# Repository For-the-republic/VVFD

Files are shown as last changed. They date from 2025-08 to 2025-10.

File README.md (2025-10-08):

# VVFD
 Variable VFD display driver for any electromagnet based VFD.
 made by Sam Ramsay and Luke Quigley
# PREREQUISTES

## It must have a leakage current
VFDs are funny little things, as even though the have vacumn in the name, most are not a pure vacumn. instead they have a small amount of gas in them. this is only true for larger ( or more delacite ones), and is the main operation which we are measuring to find the anode connections.

## how to tell if you have a leakage current
the best way to tell if it has a leakage current is by the datasheet. if it has **both** a current draw on the segment and grid, you have a leakage. 

the next best way to tell is by the size of the VFD. smaller VFDs tend to be pure vacumns, and dont have a leakage current. if it is a larger (or older) VFD like those found in audio amplifiers, car radios ect, it most likely has a leakage current.

the third and final way to tell is to manually check. if there is a leakage current, **there will be a small current increase when a valid grid/segment combination is found**. this is by far the best way to tell, however can be quite finnicky and so we reccomend the other ways first.

# how this works
 it detects a leakage in current across different pins, and will make an anode connection table accordingly.
  this is still in development so it might take a while to get up and running.

# setup process and PCB information
the PCB is designed to be cascaded for extra modules to fit your VFD size. each module can have 32 pins, and only requires the cascade/vfd driver components. the original board will still need the drivers, but no other ones will.
## setup information
the two values you will need to change  are:
- PINCOUNT
PINCOUNT is the number of shift registers used, starting from the main module and cascading to the right. we need to know this so we can properly push the right bits.

compile this code to your arduino, and have it plugged in to accept serial out. the arduino will print your matrix to the serial out, so its kinda important.

to set the base conditions, the the arduino runs it will go into setup mode for one minute. this gives you time to ajust the variable resistors, and make sure everything is working. **DO NOT CHANGE THE RESISTORS AFTER ONE MINUTE**, or else the ammeters wont have a base value to test off of.
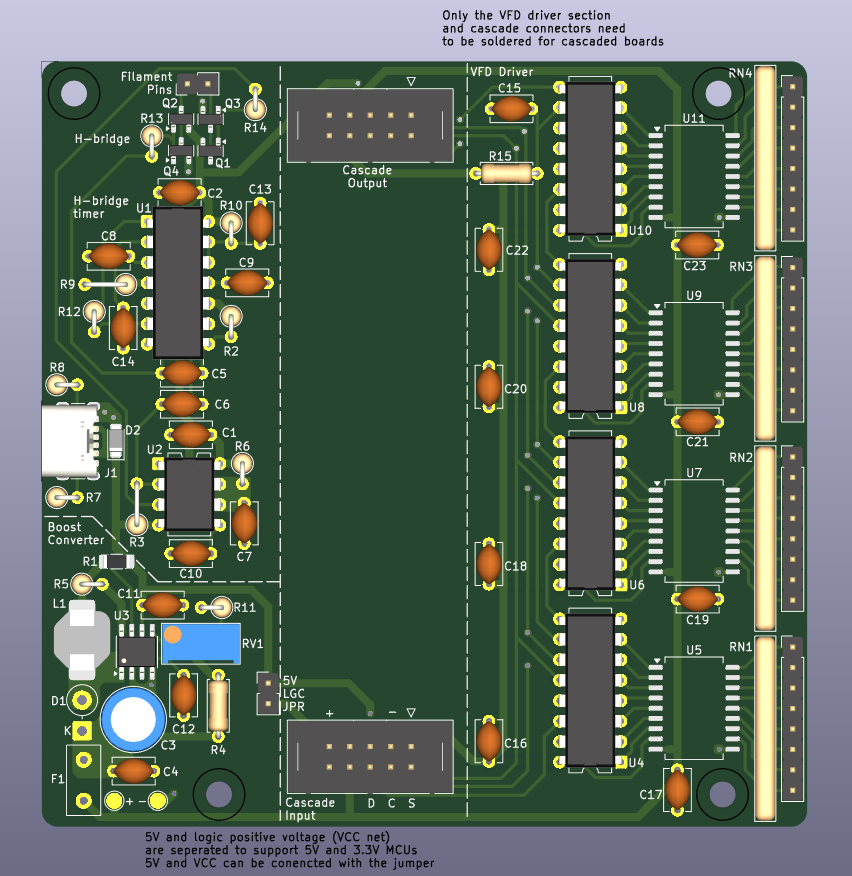
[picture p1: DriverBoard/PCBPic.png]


once this mode is done, just leave it. 
## when it has finished
once it has completed making the pinout table, it will cycle through every valid combonation and send a matrix to the serial out of the arduino.

## a note about pinouts
**if in doubt, use the pinout schematic/PCB provided**
- the AC generator pins must be both PWN pins
- the ammeter pins must be analouge
- all other pins should combos should be fine

[video of it working](https://youtu.be/ehEdY2yYjXk)

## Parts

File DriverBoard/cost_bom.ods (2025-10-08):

Reference | Qty | Value | Footprint | Master Component | Digikey Part No | Manufacturer Part No | Unit Price ($) | UC Component | Master UC Components ($) | Master DigiKey Components ($) | Cascade UC Components ($) | Cascade DigiKey Components ($) |  | User Exclude
C1,C2,C4,C11,C15,C16,C17,C18,C19,C20,C21,C22,C23 | 13 | 100n | Capacitor_THT:C_Disc_D5.1mm_W3.2mm_P5.00mm | 0 | UC |  | 0.2 | 1 | 0 | 0 | 2.6 | 0 |  | 0
C3 | 1 | 100u | Capacitor_THT:C_Radial_D8.0mm_H11.5mm_P3.50mm | 1 | 732-9051-1-ND | 860080674009 | 0.7245 | 0 | 0 | 0.7245 | 0 | 0 |  | 0
C5,C6,C8,C9,C10,C13 | 6 | 10n | Capacitor_THT:C_Disc_D5.1mm_W3.2mm_P5.00mm | 1 | UC |  | 0.2 | 1 | 1.2 | 0 | 0 | 0 |  | 0
C7,C14 | 2 | 220n | Capacitor_THT:C_Disc_D5.1mm_W3.2mm_P5.00mm | 1 | UC |  | 0.4 | 1 | 0.8 | 0 | 0 | 0 |  | 0
C12 | 1 | 330p | Capacitor_THT:C_Disc_D5.1mm_W3.2mm_P5.00mm | 1 | UC |  | 0.2 | 1 | 0.2 | 0 | 0 | 0 |  | 0
D1 | 1 | SB240L | Diode_THT:D_DO-15_P3.81mm_Vertical_KathodeUp | 1 | UC | SB240L | 0.8 | 1 | 0.8 | 0 | 0 | 0 |  | 0
D2 | 1 | SMF5V0A | Diode_SMD:D_SMF | 1 | 4878-SMF5.0ACT-ND | SMF5.0A | 0.5175 | 0 | 0 | 0.5175 | 0 | 0 |  | 0
F1 | 1 | 100mA hold | Fuse:Fuse_Littelfuse_395Series | 1 | UC | TRF250-120 | 1.2 | 1 | 1.2 | 0 | 0 | 0 |  | 0
J1 | 1 | USB_C_Receptacle_USB2.0_14P | Connector_USB:USB_C_Receptacle_GCT_USB4125-xx-x-0190_6P_TopMnt_Horizontal | 1 | 2223-UJC-H-G-SMT-P6-TRCT-ND | UJC-H-G-SMT-P6-TR | 0.851 | 0 | 0 | 0.851 | 0 | 0 |  | 0
J2 | 1 | Conn_01x02_Pin | Connector_PinHeader_2.54mm:PinHeader_1x02_P2.54mm_Vertical | 1 | UC |  | 0 | 1 | 0 | 0 | 0 | 0 |  | 0
J3,J4 | 2 | Conn_02x05_Counter_Clockwise | Connector_IDC:IDC-Header_2x05_P2.54mm_Vertical | 0 | UC |  | 0.45 | 1 | 0 | 0 | 0.9 | 0 |  | 0
J5,J6,J7,J8 | 4 | Conn_01x08_Pin | Connector_PinHeader_2.54mm:PinHeader_1x08_P2.54mm_Vertical | 0 | UC |  | 0.15 | 1 | 0 | 0 | 0.6 | 0 |  | 0
JP1 | 1 | Jumper_2_Open | Connector_PinHeader_2.54mm:PinHeader_1x02_P2.54mm_Vertical | 1 | UC |  | 0 | 1 | 0 | 0 | 0 | 0 |  | 0
L1 | 1 | 100uH | Custom:SPM7054VT-D | 1 | 445-180962-1-ND | SPM7054VT-101M-D | 2.6105 | 0 | 0 | 2.6105 | 0 | 0 |  | 0
Q1,Q2 | 2 | DMG2305UX | Package_TO_SOT_SMD:SOT-23 | 1 | DMG2305UX-7DICT-ND | DMG2305UX-7 | 0.3565 | 0 | 0 | 0.713 | 0 | 0 |  | 0
Q3,Q4 | 2 | SL3402 | Package_TO_SOT_SMD:SOT-23 | 1 | 5399-SL3402CT-ND | SL3402 | 0.3335 | 0 | 0 | 0.667 | 0 | 0 |  | 0
R1 | 1 | 0.2R | Resistor_SMD:R_1206_3216Metric_Pad1.30x1.75mm_HandSolder | 1 | 283-MFHA1206R2000FCCT-ND | MFHA1206R2000FC | 0.506 | 0 | 0 | 0.506 | 0 | 0 |  | 0
R2 | 1 | 3k3 | Resistor_THT:R_Axial_DIN0207_L6.3mm_D2.5mm_P2.54mm_Vertical | 1 | UC |  | 0 | 1 | 0 | 0 | 0 | 0 |  | 0
R3 | 1 | 3k3 | Resistor_THT:R_Axial_DIN0207_L6.3mm_D2.5mm_P5.08mm_Vertical | 1 | UC |  | 0 | 1 | 0 | 0 | 0 | 0 |  | 0
R4 | 1 | 100k | Resistor_THT:R_Axial_DIN0207_L6.3mm_D2.5mm_P7.62mm_Horizontal | 1 | UC |  | 0 | 1 | 0 | 0 | 0 | 0 |  | 0
R5 | 1 | 180R | Resistor_THT:R_Axial_DIN0207_L6.3mm_D2.5mm_P2.54mm_Vertical | 1 | UC |  | 0 | 1 | 0 | 0 | 0 | 0 |  | 0
R6 | 1 | 39k | Resistor_THT:R_Axial_DIN0207_L6.3mm_D2.5mm_P2.54mm_Vertical | 1 | UC |  | 0 | 1 | 0 | 0 | 0 | 0 |  | 0
R7,R8 | 2 | 5k1 | Resistor_THT:R_Axial_DIN0207_L6.3mm_D2.5mm_P2.54mm_Vertical | 1 | UC |  | 0 | 1 | 0 | 0 | 0 | 0 |  | 0
R9 | 1 | 1k | Resistor_THT:R_Axial_DIN0207_L6.3mm_D2.5mm_P5.08mm_Vertical | 1 | UC |  | 0 | 1 | 0 | 0 | 0 | 0 |  | 0
R10 | 1 | 10k | Resistor_THT:R_Axial_DIN0207_L6.3mm_D2.5mm_P2.54mm_Vertical | 1 | UC |  | 0 | 1 | 0 | 0 | 0 | 0 |  | 0
R11 | 1 | 3k9 | Resistor_THT:R_Axial_DIN0207_L6.3mm_D2.5mm_P2.54mm_Vertical | 1 | UC |  | 0 | 1 | 0 | 0 | 0 | 0 |  | 0
R12 | 1 | 68k | Resistor_THT:R_Axial_DIN0207_L6.3mm_D2.5mm_P2.54mm_Vertical | 1 | UC |  | 0 | 1 | 0 | 0 | 0 | 0 |  | 0
R13,R14 | 2 | 2K2 | Resistor_THT:R_Axial_DIN0207_L6.3mm_D2.5mm_P2.54mm_Vertical | 1 | UC |  | 0 | 1 | 0 | 0 | 0 | 0 |  | 0
R15 | 1 | 10k | Resistor_THT:R_Axial_DIN0207_L6.3mm_D2.5mm_P7.62mm_Horizontal | 1 | UC |  | 0 | 1 | 0 | 0 | 0 | 0 |  | 0
RN1,RN2,RN3,RN4 | 4 | 1M | Resistor_THT:R_Array_SIP9 | 0 | 4609X-101-474LF-ND | 4609X-101-474LF | 0.9085 | 0 | 0 | 0 | 0 | 0 |  | 1
RV1 | 1 | 10k | Potentiometer_THT:Potentiometer_Bourns_3296W_Vertical | 1 | UC | 3296W | 3 | 1 | 3 | 0 | 0 | 0 |  | 0
U1 | 1 | LM556 | Package_DIP:DIP-14_W7.62mm | 1 | UC | LM557 | 1 | 1 | 1 | 0 | 0 | 0 |  | 0
U2 | 1 | LM555xN | Package_DIP:DIP-8_W7.62mm | 1 | UC | LM555 | 3 | 1 | 3 | 0 | 0 | 0 |  | 0
U3 | 1 | MC34063AD | Package_SO:SOIC-8_3.9x4.9mm_P1.27mm | 1 | 5399-MC34063SCT-ND | MC34063S | 0.5405 | 0 | 0 | 0.5405 | 0 | 0 |  | 0
U4,U6,U8,U10 | 4 | 74HC595 | Package_DIP:DIP-16_W7.62mm | 0 | UC | 74HC595 | 1.2 | 1 | 0 | 0 | 4.8 | 0 |  | 0
U5,U7,U9,U11 | 4 | TBD62783A | Package_SO:SOP-18_7x12.5mm_P1.27mm | 0 | TBD62783AFGELCT-ND | TBD62783AFG,EL | 4.876 | 0 | 0 | 0 | 0 | 19.504 |  | 0
 |  |  |  |  |  |  |  | 0 | 0 | 0 | 0 | 0 |  | 0
 |  |  |  |  |  |  |  | 0 | 0 | 0 | 0 | 0 |  | 0
 |  |  |  |  |  |  |  | 0 | 0 | 0 | 0 | 0 |  | 0
 |  |  |  |  |  |  |  | 0 | 0 | 0 | 0 | 0 |  | 0
 |  |  |  |  |  |  |  | 0 | 0 | 0 | 0 | 0 |  | 0
 |  |  |  |  |  |  |  | 0 | 0 | 0 | 0 | 0 |  | 0
 |  |  |  |  |  |  |  | 0 | 0 | 0 | 0 | 0 |  | 0
 |  |  |  |  |  |  |  | 0 | 0 | 0 | 0 | 0 |  | 0
 |  |  |  |  |  |  |  | 0 | 0 | 0 | 0 | 0 |  | 0
 |  |  |  |  |  |  |  | 0 | 0 | 0 | 0 | 0 |  | 0
 |  |  |  |  |  |  |  | 0 | 0 | 0 | 0 | 0 |  | 0
Kicad BOM goes here ^ |  |  |  |  |  |  |  |  | 11.2 | 7.13 | 8.9 | 19.504 |  | 0
 |  |  |  |  |  |  |  |  | Master Board ($) | Cascade Board ($) |  | # Boards | 2
 |  |  |  |  |  |  |  | UC | 11.2 | 8.9 |  | VFD driver pins | 64
 |  |  |  |  |  |  |  | DigiKey | 7.13 | 19.504 |  | Total Price ($) | 75.138
 |  |  |  |  |  |  |  | Total | 18.33 | 28.404
 |  |  |  |  |  |  |  |  | The master board total doesn’t include the cascade parts
 |  |  |  |  |  |  |  |  | A master board would of course need cascade parts added
 |  |  |  |  |  |  |  |  | So the true cost of a master baord is:
 |  |  |  |  |  |  |  |  | 46.734

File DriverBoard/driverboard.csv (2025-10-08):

Reference | Qty | Value | Footprint | Master Component | Digikey Part No | Manufacturer Part No | Unit Price ($)
C1,C2,C4,C11,C15,C16,C17,C18,C19,C20,C21,C22,C23 | 13 | 100n | Capacitor_THT:C_Disc_D5.1mm_W3.2mm_P5.00mm | 0 | UC |  | 0.20
C3 | 1 | 100u | Capacitor_THT:C_Radial_D8.0mm_H11.5mm_P3.50mm | 1 | 732-9051-1-ND | 860080674009 | 0.72450
C5,C6,C8,C9,C10,C13 | 6 | 10n | Capacitor_THT:C_Disc_D5.1mm_W3.2mm_P5.00mm | 1 | UC |  | 0.20
C7,C14 | 2 | 220n | Capacitor_THT:C_Disc_D5.1mm_W3.2mm_P5.00mm | 1 | UC |  | 0.40
C12 | 1 | 330p | Capacitor_THT:C_Disc_D5.1mm_W3.2mm_P5.00mm | 1 | UC |  | 0.20
D1 | 1 | SB240L | Diode_THT:D_DO-15_P3.81mm_Vertical_KathodeUp | 1 | UC | SB240L | 0.80
D2 | 1 | SMF5V0A | Diode_SMD:D_SMF | 1 | 4878-SMF5.0ACT-ND | SMF5.0A | 0.51750
F1 | 1 | 100mA hold | Fuse:Fuse_Littelfuse_395Series | 1 | UC | TRF250-120 | 1.20
J1 | 1 | USB_C_Receptacle_USB2.0_14P | Connector_USB:USB_C_Receptacle_GCT_USB4125-xx-x-0190_6P_TopMnt_Horizontal | 1 | 2223-UJC-H-G-SMT-P6-TRCT-ND | UJC-H-G-SMT-P6-TR | 0.85100
J2 | 1 | Conn_01x02_Pin | Connector_PinHeader_2.54mm:PinHeader_1x02_P2.54mm_Vertical | 1 | UC |  | 0.00
J3,J4 | 2 | Conn_02x05_Counter_Clockwise | Connector_IDC:IDC-Header_2x05_P2.54mm_Vertical | 0 | UC |  | 0.45
J5,J6,J7,J8 | 4 | Conn_01x08_Pin | Connector_PinHeader_2.54mm:PinHeader_1x08_P2.54mm_Vertical | 0 | UC |  | 0.15
JP1 | 1 | Jumper_2_Open | Connector_PinHeader_2.54mm:PinHeader_1x02_P2.54mm_Vertical | 1 | UC |  | 0.00
L1 | 1 | 100uH | Custom:SPM7054VT-D | 1 | 445-180962-1-ND | SPM7054VT-101M-D | 2.61050
Q1,Q2 | 2 | DMG2305UX | Package_TO_SOT_SMD:SOT-23 | 1 | DMG2305UX-7DICT-ND | DMG2305UX-7 | 0.35650
Q3,Q4 | 2 | SL3402 | Package_TO_SOT_SMD:SOT-23 | 1 | 5399-SL3402CT-ND | SL3402 | 0.33350
R1 | 1 | 0.2R | Resistor_SMD:R_1206_3216Metric_Pad1.30x1.75mm_HandSolder | 1 | 283-MFHA1206R2000FCCT-ND | MFHA1206R2000FC | 0.506
R2 | 1 | 3k3 | Resistor_THT:R_Axial_DIN0207_L6.3mm_D2.5mm_P2.54mm_Vertical | 1 | UC |  | 0.00
R3 | 1 | 3k3 | Resistor_THT:R_Axial_DIN0207_L6.3mm_D2.5mm_P5.08mm_Vertical | 1 | UC |  | 0.00
R4 | 1 | 100k | Resistor_THT:R_Axial_DIN0207_L6.3mm_D2.5mm_P7.62mm_Horizontal | 1 | UC |  | 0.00
R5 | 1 | 180R | Resistor_THT:R_Axial_DIN0207_L6.3mm_D2.5mm_P2.54mm_Vertical | 1 | UC |  | 0.00
R6 | 1 | 39k | Resistor_THT:R_Axial_DIN0207_L6.3mm_D2.5mm_P2.54mm_Vertical | 1 | UC |  | 0.00
R7,R8 | 2 | 5k1 | Resistor_THT:R_Axial_DIN0207_L6.3mm_D2.5mm_P2.54mm_Vertical | 1 | UC |  | 0.00
R9 | 1 | 1k | Resistor_THT:R_Axial_DIN0207_L6.3mm_D2.5mm_P5.08mm_Vertical | 1 | UC |  | 0.00
R10 | 1 | 10k | Resistor_THT:R_Axial_DIN0207_L6.3mm_D2.5mm_P2.54mm_Vertical | 1 | UC |  | 0.00
R11 | 1 | 3k9 | Resistor_THT:R_Axial_DIN0207_L6.3mm_D2.5mm_P2.54mm_Vertical | 1 | UC |  | 0.00
R12 | 1 | 68k | Resistor_THT:R_Axial_DIN0207_L6.3mm_D2.5mm_P2.54mm_Vertical | 1 | UC |  | 0.00
R13,R14 | 2 | 2K2 | Resistor_THT:R_Axial_DIN0207_L6.3mm_D2.5mm_P2.54mm_Vertical | 1 | UC |  | 0.00
R15 | 1 | 10k | Resistor_THT:R_Axial_DIN0207_L6.3mm_D2.5mm_P7.62mm_Horizontal | 1 | UC |  | 0.00
RN1,RN2,RN3,RN4 | 4 | 1M | Resistor_THT:R_Array_SIP9 | 0 | 4609X-101-474LF-ND | 4609X-101-474LF | 0.9085
RV1 | 1 | 10k | Potentiometer_THT:Potentiometer_Bourns_3296W_Vertical | 1 | UC | 3296W | 3.00
U1 | 1 | LM556 | Package_DIP:DIP-14_W7.62mm | 1 | UC | LM557 | 1.00
U2 | 1 | LM555xN | Package_DIP:DIP-8_W7.62mm | 1 | UC | LM555 | 3
U3 | 1 | MC34063AD | Package_SO:SOIC-8_3.9x4.9mm_P1.27mm | 1 | 5399-MC34063SCT-ND | MC34063S | 0.54050
U4,U6,U8,U10 | 4 | 74HC595 | Package_DIP:DIP-16_W7.62mm | 0 | UC | 74HC595 | 1.20
U5,U7,U9,U11 | 4 | TBD62783A | Package_SO:SOP-18_7x12.5mm_P1.27mm | 0 | TBD62783AFGELCT-ND | TBD62783AFG,EL | 4.87600

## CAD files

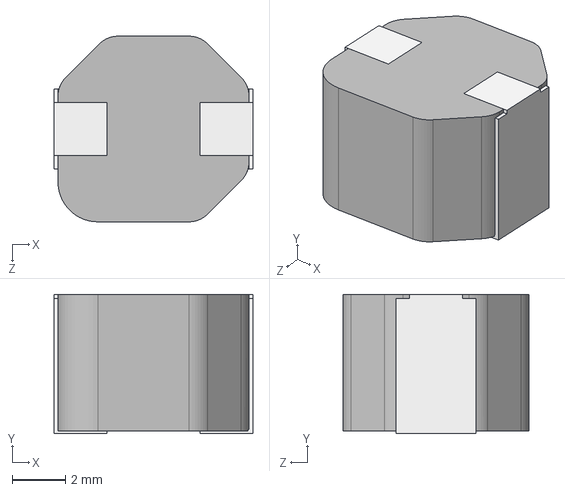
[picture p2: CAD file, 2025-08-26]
DriverBoard/3D/spm7054vt-d.step
7.50 x 5.25 x 7.00 mm
Mold_7054
Terminal_7054 x 2

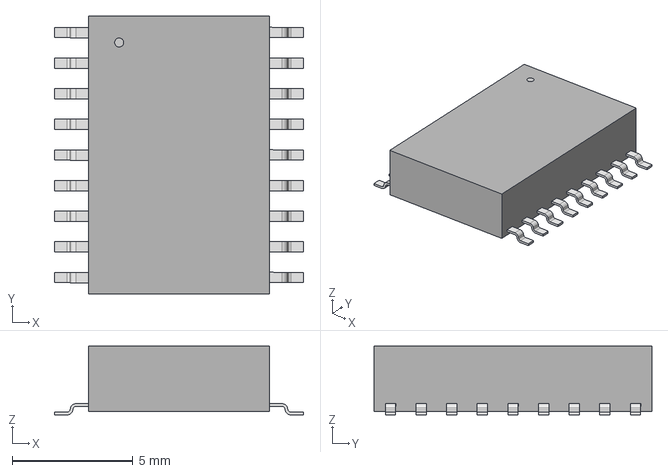
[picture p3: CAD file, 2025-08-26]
DriverBoard/3D/P-SOP18-0812-1p27-001_TOS.step
10.3 x 11.5 x 2.85 mm

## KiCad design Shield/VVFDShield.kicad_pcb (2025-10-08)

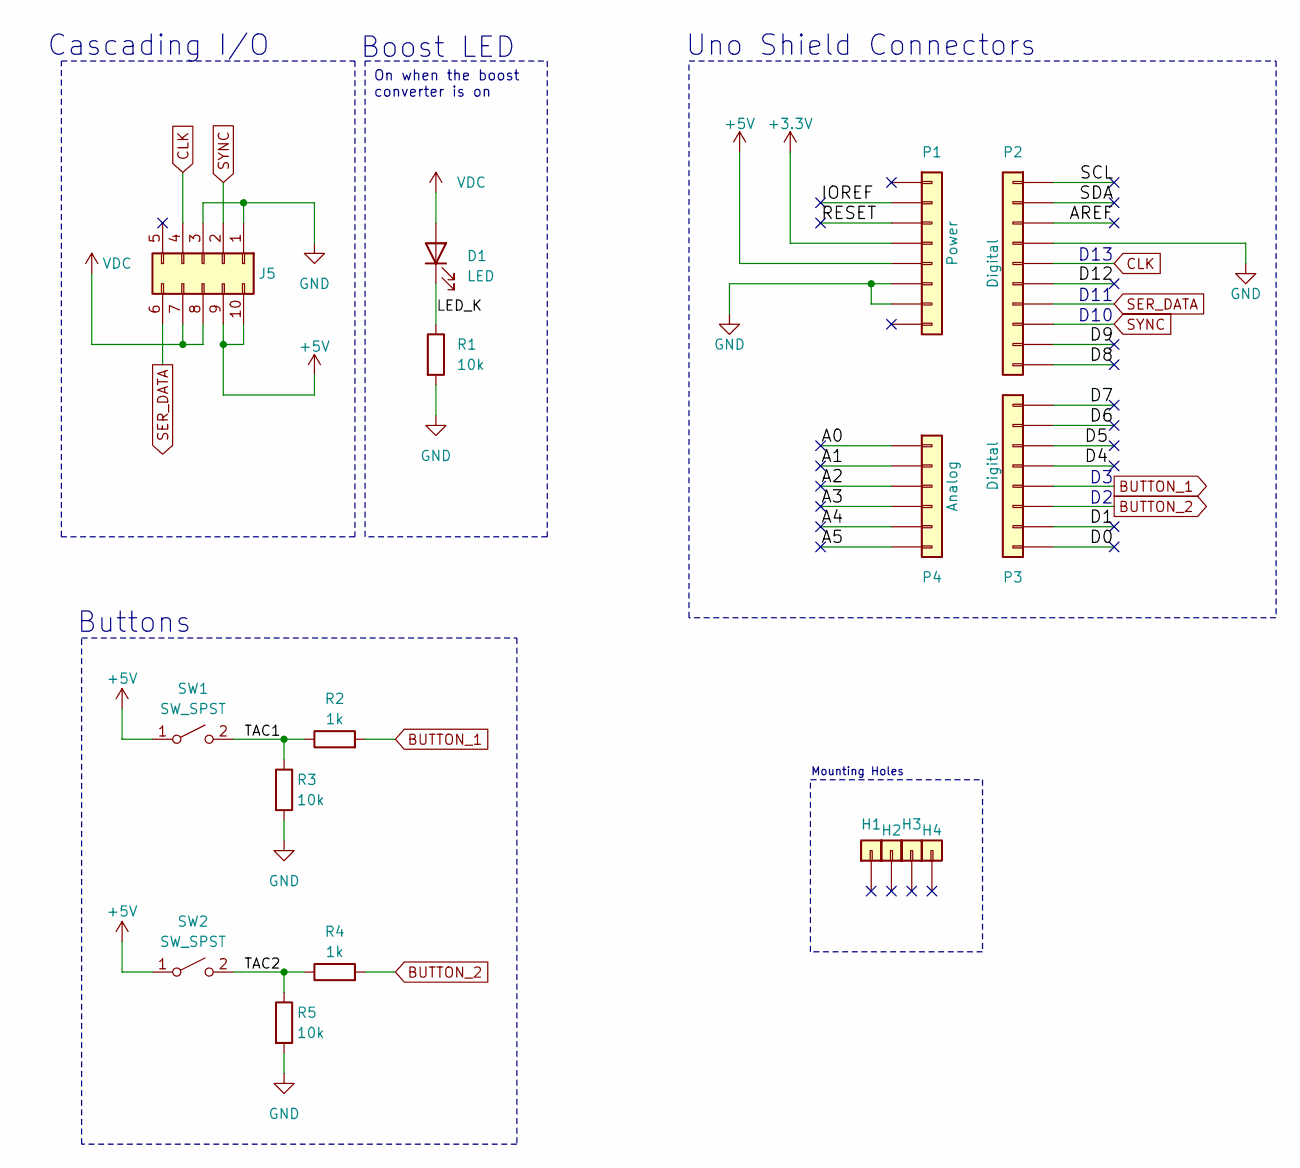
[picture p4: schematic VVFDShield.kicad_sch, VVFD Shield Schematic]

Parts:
D1: LED; LED_D5.0mm
H1, H2, H3, H4: CONN_01X01; Mounting_Hole
J5: Conn_02x05_Counter_Clockwise; IDC-Header_2x05_P2.54mm_Vertical; Digikey Part No UC
P1: Power; Socket_Strip_Arduino_1x08
P2: Digital; Socket_Strip_Arduino_1x10
P3: Digital; Socket_Strip_Arduino_1x08
P4: Analog; Socket_Strip_Arduino_1x06
R1, R3, R5: 10k; R_Axial_DIN0207_L6.3mm_D2.5mm_P7.62mm_Horizontal
R2, R4: 1k; R_Axial_DIN0207_L6.3mm_D2.5mm_P7.62mm_Horizontal
SW1, SW2: SW_SPST; SW_PUSH_6mm

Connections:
+3.3V: P1.4
+5V: J5.9, J5.10, P1.5, SW1.1 (A), SW2.1 (A)
/A0: P4.1
/A1: P4.2
/A2: P4.3
/A3: P4.4
/A4: P4.5
/A5: P4.6
/AREF: P2.3
/D0: P3.8
/D1: P3.7
/D4: P3.4
/D5: P3.3
/D6: P3.2
/D7: P3.1
/D8: P2.10
/D9: P2.9
/D12: P2.6
/IOREF: P1.2
/LED_K: D1.1 (K), R1.1
/RESET: P1.3
/SCL: P2.1
/SDA: P2.2
/TAC1: R2.1, R3.1, SW1.2 (B)
/TAC2: R4.1, R5.1, SW2.2 (B)
BUTTON_1: P3.5, R2.2
BUTTON_2: P3.6, R4.2
CLK: J5.4, P2.5
GND: J5.1, J5.3, P1.6, P1.7, P2.4, R1.2, R3.2, R5.2
SER_DATA: J5.6, P2.7
SYNC: J5.2, P2.8
VDC: D1.2 (A), J5.7, J5.8

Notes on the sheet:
Cascading I/O
Uno Shield Connectors
Buttons
Boost LED
D13
Mounting Holes
D10
D11
On when the boost converter is on

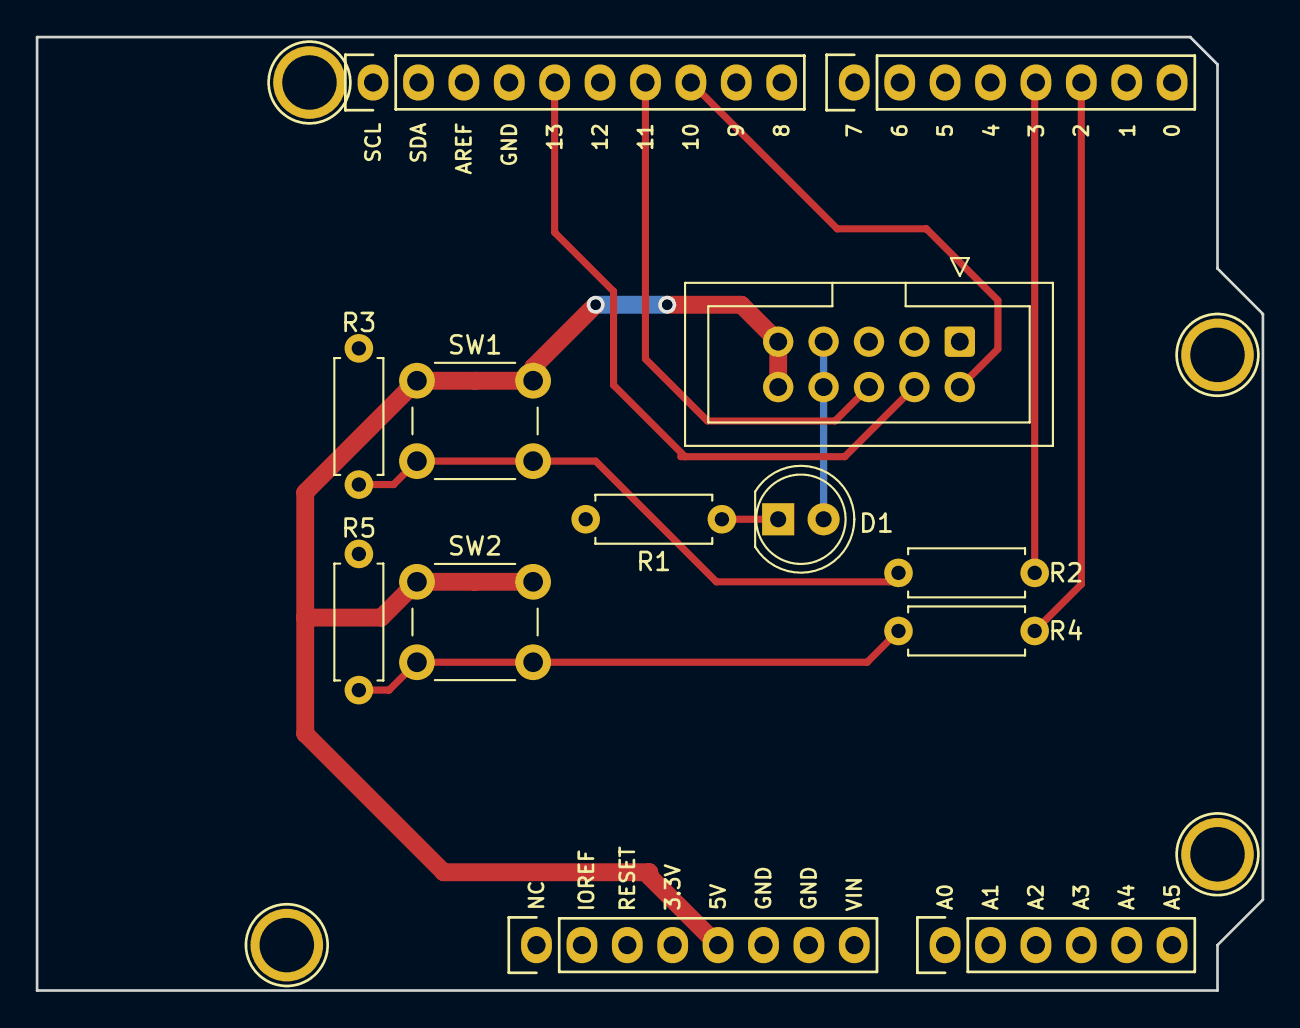
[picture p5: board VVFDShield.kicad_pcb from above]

Board: 2 copper layers, 68.6 x 53.3 mm, 17 parts (0 on the bottom side), 11 nets.

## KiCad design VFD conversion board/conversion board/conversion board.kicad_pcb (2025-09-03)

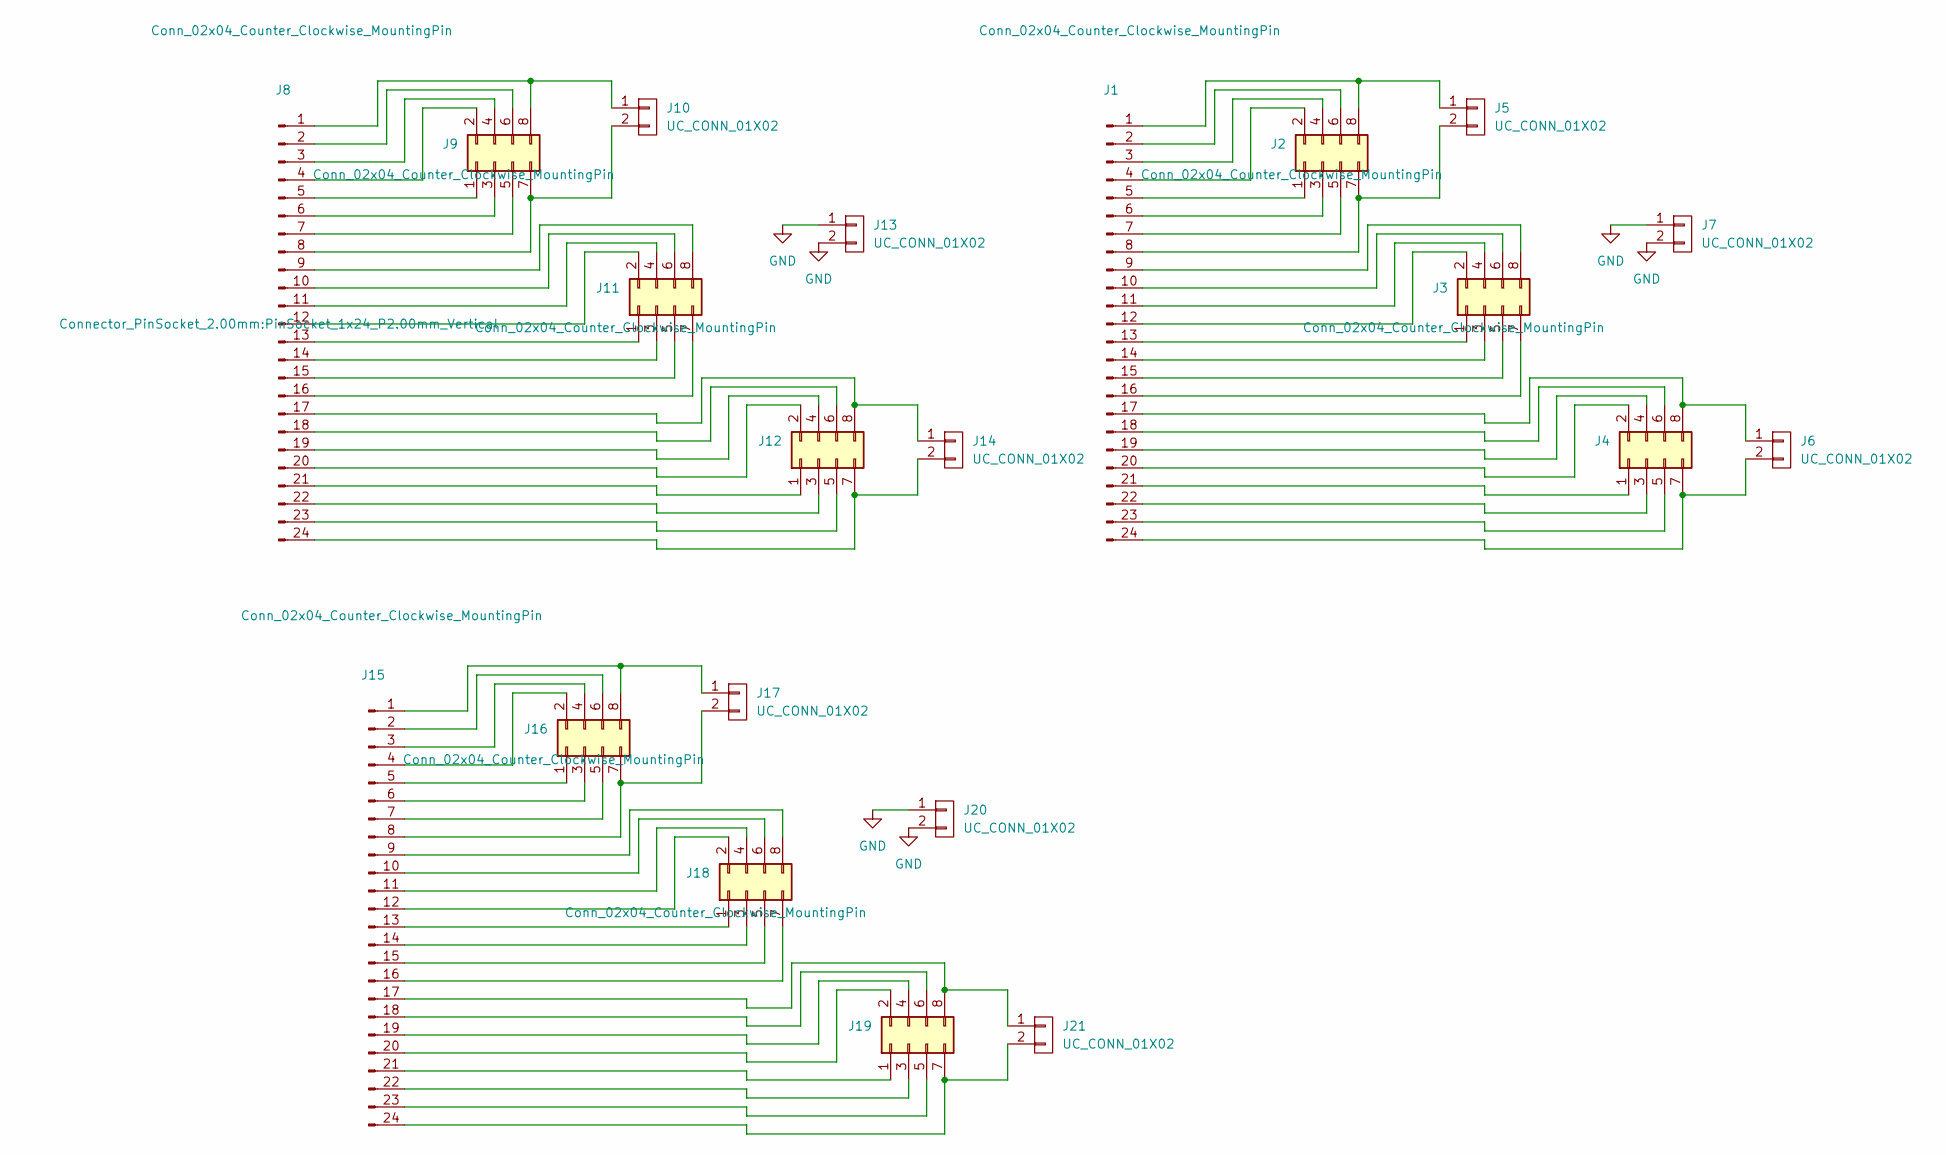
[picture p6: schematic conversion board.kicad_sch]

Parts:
J1, J8, J15: Conn_01x24_Pin; PinSocket_1x24_P2.00mm_Vertical
J2, J3, J4, J9, J11, J12, J16, J18, J19: Conn_02x04_Counter_Clockwise_MountingPin; PinHeader_2x04_P2.54mm_Vertical
J5, J6, J7, J10, J13, J14, J17, J20, J21: UC_CONN_01X02; PinHeader_1x02_P2.54mm_Vertical

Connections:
GND: J7.1, J7.2, J13.1, J13.2, J20.1, J20.2
unnamed: J1.1, J2.8, J5.1
unnamed: J1.2, J2.6
unnamed: J1.3, J2.4
unnamed: J1.4, J2.2
unnamed: J1.5, J2.1
unnamed: J1.6, J2.3
unnamed: J1.7, J2.5
unnamed: J1.8, J2.7, J5.2
unnamed: J1.9, J3.8
unnamed: J1.10, J3.6
unnamed: J1.11, J3.4
unnamed: J1.12, J3.2
unnamed: J1.13, J3.1
unnamed: J1.14, J3.3
unnamed: J1.15, J3.5
unnamed: J1.16, J3.7
unnamed: J1.17, J4.8, J6.1
unnamed: J1.18, J4.6
unnamed: J1.19, J4.4
unnamed: J1.20, J4.2
unnamed: J1.21, J4.1
unnamed: J1.22, J4.3
unnamed: J1.23, J4.5
unnamed: J1.24, J4.7, J6.2
unnamed: J8.2, J9.6
unnamed: J8.3, J9.4
unnamed: J8.4, J9.2
unnamed: J8.5, J9.1
unnamed: J8.6, J9.3
unnamed: J8.7, J9.5
unnamed: J8.1, J9.8, J10.1
unnamed: J8.8, J9.7, J10.2
unnamed: J8.13, J11.1
unnamed: J8.12, J11.2
unnamed: J8.14, J11.3
unnamed: J8.11, J11.4
unnamed: J8.15, J11.5
unnamed: J8.10, J11.6
unnamed: J8.16, J11.7
unnamed: J8.9, J11.8
unnamed: J8.21, J12.1
unnamed: J8.20, J12.2
unnamed: J8.22, J12.3
unnamed: J8.19, J12.4
unnamed: J8.23, J12.5
unnamed: J8.18, J12.6
unnamed: J8.24, J12.7, J14.2
unnamed: J8.17, J12.8, J14.1
unnamed: J15.1, J16.8, J17.1
unnamed: J15.2, J16.6
unnamed: J15.3, J16.4
unnamed: J15.4, J16.2
unnamed: J15.5, J16.1
unnamed: J15.6, J16.3
unnamed: J15.7, J16.5
unnamed: J15.8, J16.7, J17.2
unnamed: J15.9, J18.8
unnamed: J15.10, J18.6
unnamed: J15.11, J18.4
unnamed: J15.12, J18.2
unnamed: J15.13, J18.1
unnamed: J15.14, J18.3
unnamed: J15.15, J18.5
unnamed: J15.16, J18.7
unnamed: J15.17, J19.8, J21.1
unnamed: J15.18, J19.6
unnamed: J15.19, J19.4
unnamed: J15.20, J19.2
unnamed: J15.21, J19.1
unnamed: J15.22, J19.3
unnamed: J15.23, J19.5
unnamed: J15.24, J19.7, J21.2

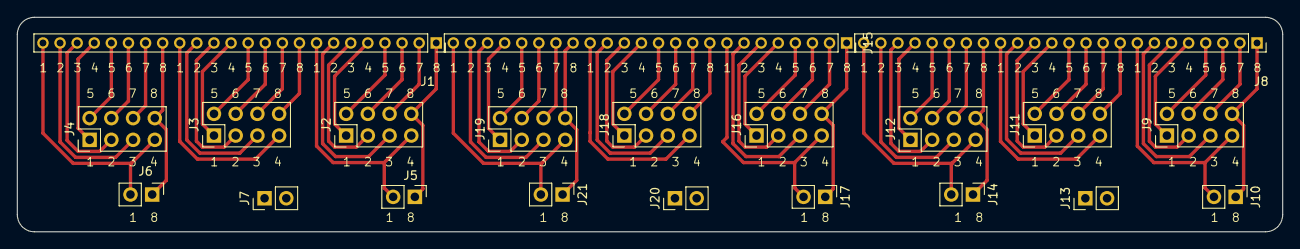
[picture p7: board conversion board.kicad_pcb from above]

Board: 2 copper layers, 148.0 x 25.1 mm, 21 parts (0 on the bottom side), 73 nets.

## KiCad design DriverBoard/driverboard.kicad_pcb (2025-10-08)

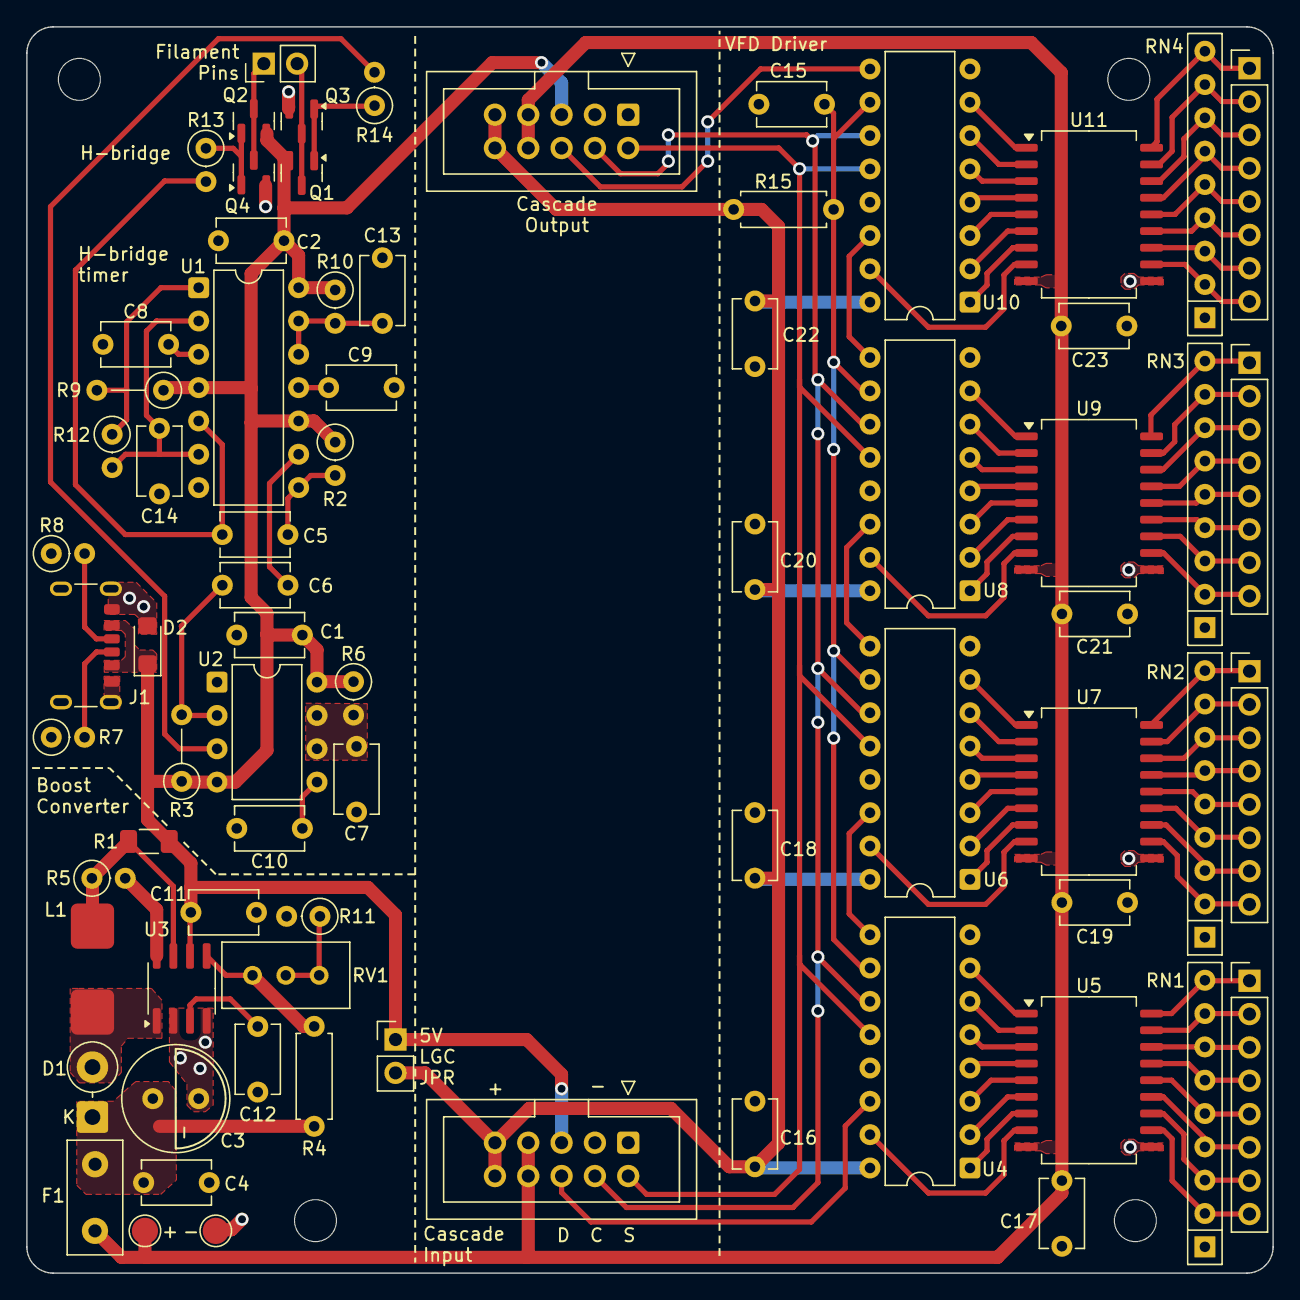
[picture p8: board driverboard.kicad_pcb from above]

Board: 2 copper layers, 95.0 x 95.0 mm, 77 parts (0 on the bottom side), 101 nets.

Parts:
C1, C2, C4, C11, C15, C16, C17, C18, C19, C20, C21, C22, C23: 100n; C_Disc_D5.1mm_W3.2mm_P5.00mm
C3: 100u; C_Radial_D8.0mm_H11.5mm_P3.50mm
C5, C6, C8, C9, C10, C13: 10n; C_Disc_D5.1mm_W3.2mm_P5.00mm
C7, C14: 220n; C_Disc_D5.1mm_W3.2mm_P5.00mm
C12: 330p; C_Disc_D5.1mm_W3.2mm_P5.00mm
D1: SB240L; D_DO-15_P3.81mm_Vertical_KathodeUp
D2: SMF5V0A; D_SMF
F1: 100mA hold; Fuse_Littelfuse_395Series
H1, H2, H3, H4: MountingHole; MountingHole_3.2mm_M3
J1: USB_C_Receptacle_USB2.0_14P; USB_C_Receptacle_GCT_USB4125-xx-x-0190_6P_TopMnt_Horizontal
J2: Conn_01x02_Pin; PinHeader_1x02_P2.54mm_Vertical
J3, J4: Conn_02x05_Counter_Clockwise; IDC-Header_2x05_P2.54mm_Vertical
J5, J6, J7, J8: Conn_01x08_Pin; PinHeader_1x08_P2.54mm_Vertical
JP1: Jumper_2_Open; PinHeader_1x02_P2.54mm_Vertical
L1: 100uH; SPM7054VT-D
Q1, Q2: DMG2305UX; SOT-23
Q3, Q4: SL3402; SOT-23
R1: 0.2R; R_1206_3216Metric_Pad1.30x1.75mm_HandSolder
R2: 3k3; R_Axial_DIN0207_L6.3mm_D2.5mm_P2.54mm_Vertical
R3: 3k3; R_Axial_DIN0207_L6.3mm_D2.5mm_P5.08mm_Vertical
R4: 100k; R_Axial_DIN0207_L6.3mm_D2.5mm_P7.62mm_Horizontal
R5: 180R; R_Axial_DIN0207_L6.3mm_D2.5mm_P2.54mm_Vertical
R6: 39k; R_Axial_DIN0207_L6.3mm_D2.5mm_P2.54mm_Vertical
R7, R8: 5k1; R_Axial_DIN0207_L6.3mm_D2.5mm_P2.54mm_Vertical
R9: 1k; R_Axial_DIN0207_L6.3mm_D2.5mm_P5.08mm_Vertical
R10: 10k; R_Axial_DIN0207_L6.3mm_D2.5mm_P2.54mm_Vertical
R11: 3k9; R_Axial_DIN0207_L6.3mm_D2.5mm_P2.54mm_Vertical
R12: 68k; R_Axial_DIN0207_L6.3mm_D2.5mm_P2.54mm_Vertical
R13, R14: 2K2; R_Axial_DIN0207_L6.3mm_D2.5mm_P2.54mm_Vertical
R15: 10k; R_Axial_DIN0207_L6.3mm_D2.5mm_P7.62mm_Horizontal
RN1, RN2, RN3, RN4: 1M; R_Array_SIP9
RV1: 10k; Potentiometer_Bourns_3296W_Vertical
TP1, TP2: TestPoint; TestPoint_Pad_D2.0mm
U1: LM556; DIP-14_W7.62mm
U2: LM555xN; DIP-8_W7.62mm
U3: MC34063AD; SOIC-8_3.9x4.9mm_P1.27mm
U4, U6, U8, U10: 74HC595; DIP-16_W7.62mm
U5, U7, U9, U11: TBD62783A; SOP-18_7x12.5mm_P1.27mm

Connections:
+5V: C1.1, C2.1, C11.1, D2.1 (A1), J1.A9 (VBUS), J1.B9 (VBUS), J3.5, J4.5, JP1.1 (A), Q1.2 (S), Q2.2 (S), R1.1, R2.1, R3.1, R6.1, R9.1, R10.1, U1.4 (R), U1.10 (R), U1.14 (VCC), U2.4 (R), U2.8 (VCC), U3.6 (Vin)
/BOOST_OUT: C3.1, C4.1, D1.1 (K), F1.2, R4.1
/BOOST_SW: D1.2 (A), L1.2, U3.1 (SwC)
/DRIVE_COLLECTOR: R5.2, U3.8 (DC)
/IL_SENSE: L1.1, R1.2, R5.1, U3.7 (Ipk)
/POT: R11.1, RV1.2, RV1.3
/SER_CHAIN1: U4.9 (QH'), U6.14 (SER)
/SER_CHAIN2: U6.9 (QH'), U8.14 (SER)
/SER_CHAIN3: U8.9 (QH'), U10.14 (SER)
/TC: C12.1, U3.3 (TC)
/TIMING_CAP_1: C14.1, R12.2, U1.2 (THR), U1.6 (TR)
/TIMING_CAP_2: C13.1, R10.2, U1.12 (THR), U1.13 (DIS)
/TIMING_CAP_3: C7.1, R6.2, U2.6 (THR), U2.7 (DIS)
/TIM_1_CV: C8.1, U1.3 (CV)
/TIM_1_DIS: R9.2, R12.1, U1.1 (DIS)
/TIM_2_CV: C9.1, U1.11 (CV)
/TIM_2_IN: C5.2, R2.2, U1.8 (TR)
/TIM_2_OUT: C6.1, U1.9 (Q)
/TIM_3_CV: C10.1, U2.5 (CV)
/TIM_3_IN: C6.2, R3.2, U2.2 (TR)
/VFD drive 1/A: U4.15 (QA), U5.8 (I8)
/VFD drive 1/B: U4.1 (QB), U5.7 (I7)
/VFD drive 1/C: U4.2 (QC), U5.6 (I6)
/VFD drive 1/D: U4.3 (QD), U5.5 (I5)
/VFD drive 1/E: U4.4 (QE), U5.4 (I4)
/VFD drive 1/F: U4.5 (QF), U5.3 (I3)
/VFD drive 1/G: U4.6 (QG), U5.2 (I2)
/VFD drive 1/H: U4.7 (QH), U5.1 (I1)
/VFD drive 2/A: U6.15 (QA), U7.8 (I8)
/VFD drive 2/B: U6.1 (QB), U7.7 (I7)
/VFD drive 2/C: U6.2 (QC), U7.6 (I6)
/VFD drive 2/D: U6.3 (QD), U7.5 (I5)
/VFD drive 2/E: U6.4 (QE), U7.4 (I4)
/VFD drive 2/F: U6.5 (QF), U7.3 (I3)
/VFD drive 2/G: U6.6 (QG), U7.2 (I2)
/VFD drive 2/H: U6.7 (QH), U7.1 (I1)
/VFD drive 3/A: U8.15 (QA), U9.8 (I8)
/VFD drive 3/B: U8.1 (QB), U9.7 (I7)
/VFD drive 3/C: U8.2 (QC), U9.6 (I6)
/VFD drive 3/D: U8.3 (QD), U9.5 (I5)
/VFD drive 3/E: U8.4 (QE), U9.4 (I4)
/VFD drive 3/F: U8.5 (QF), U9.3 (I3)
/VFD drive 3/G: U8.6 (QG), U9.2 (I2)
/VFD drive 3/H: U8.7 (QH), U9.1 (I1)
/VFD drive 4/A: U10.15 (QA), U11.8 (I8)
/VFD drive 4/B: U10.1 (QB), U11.7 (I7)
/VFD drive 4/C: U10.2 (QC), U11.6 (I6)
/VFD drive 4/D: U10.3 (QD), U11.5 (I5)
/VFD drive 4/E: U10.4 (QE), U11.4 (I4)
/VFD drive 4/F: U10.5 (QF), U11.3 (I3)
/VFD drive 4/G: U10.6 (QG), U11.2 (I2)
/VFD drive 4/H: U10.7 (QH), U11.1 (I1)
BRIDGE_G1: Q2.1 (G), Q4.1 (G), R13.1
BRIDGE_G2: Q1.1 (G), Q3.1 (G), R14.1
CLK: J3.4, J4.4, U4.11 (SRCLK), U6.11 (SRCLK), U8.11 (SRCLK), U10.11 (SRCLK)
CLR: C15.1, R15.1, U4.10 (~SRCLR), U6.10 (~SRCLR), U8.10 (~SRCLR), U10.10 (~SRCLR)
FILAMENT_1: J2.2, Q1.3 (D), Q3.3 (D)
FILAMENT_2: J2.1, Q2.3 (D), Q4.3 (D)
GND: C1.2, C2.2, C3.2, C4.2, C7.2, C8.2, C9.2, C10.2, C11.2, C12.2, C13.2, C14.2, C15.2, C16.2, C17.2, C18.2, C19.2, C20.2, C21.2, C22.2, C23.2, D2.2 (A2), J1.A12 (GND), J1.B12 (GND), J1.S1 (SHIELD), J3.1, J3.3, J4.1, J4.3, Q3.2 (S), Q4.2 (S), R7.1, R8.1, R11.2, RN1.1 (common), RN2.1 (common), RN3.1 (common), RN4.1 (common), TP1.1, U1.7 (GND), U2.1 (GND), U3.2 (SwE), U3.4 (GND), U4.8 (GND), U4.13 (~OE), U5.10 (GND), U6.8 (GND), U6.13 (~OE), U7.10 (GND), U8.8 (GND), U8.13 (~OE), U9.10 (GND), U10.8 (GND), U10.13 (~OE), U11.10 (GND)
H1: C5.1, R13.2, U1.5 (Q)
H2: R14.2, U2.3 (Q)
MAIN_SER_IN: J4.6, U4.14 (SER)
MAIN_SER_OUT: J3.6, U10.9 (QH')
unnamed: J1.A5 (CC1), R8.2
unnamed: J1.B5 (CC2), R7.2
unnamed: J5.1, RN1.9 (R8), U5.18 (O1)
unnamed: J5.2, RN1.8 (R7), U5.17 (O2)
unnamed: J5.3, RN1.7 (R6), U5.16 (O3)
unnamed: J5.4, RN1.6 (R5), U5.15 (O4)
unnamed: J5.5, RN1.5 (R4), U5.14 (O5)
unnamed: J5.6, RN1.4 (R3), U5.13 (O6)
unnamed: J5.7, RN1.3 (R2), U5.12 (O7)
unnamed: J5.8, RN1.2 (R1), U5.11 (O8)
unnamed: J6.1, RN2.9 (R8), U7.18 (O1)
unnamed: J6.2, RN2.8 (R7), U7.17 (O2)
unnamed: J6.3, RN2.7 (R6), U7.16 (O3)
unnamed: J6.4, RN2.6 (R5), U7.15 (O4)
unnamed: J6.5, RN2.5 (R4), U7.14 (O5)
unnamed: J6.6, RN2.4 (R3), U7.13 (O6)
unnamed: J6.7, RN2.3 (R2), U7.12 (O7)
unnamed: J6.8, RN2.2 (R1), U7.11 (O8)
unnamed: J7.1, RN3.9 (R8), U9.18 (O1)
unnamed: J7.2, RN3.8 (R7), U9.17 (O2)
unnamed: J7.3, RN3.7 (R6), U9.16 (O3)
unnamed: J7.4, RN3.6 (R5), U9.15 (O4)
unnamed: J7.5, RN3.5 (R4), U9.14 (O5)
unnamed: J7.6, RN3.4 (R3), U9.13 (O6)
unnamed: J7.7, RN3.3 (R2), U9.12 (O7)
unnamed: J7.8, RN3.2 (R1), U9.11 (O8)
unnamed: J8.1, RN4.9 (R8), U11.18 (O1)
unnamed: J8.2, RN4.8 (R7), U11.17 (O2)
unnamed: J8.3, RN4.7 (R6), U11.16 (O3)
unnamed: J8.4, RN4.6 (R5), U11.15 (O4)
unnamed: J8.5, RN4.5 (R4), U11.14 (O5)
unnamed: J8.6, RN4.4 (R3), U11.13 (O6)
unnamed: J8.7, RN4.3 (R2), U11.12 (O7)
unnamed: J8.8, RN4.2 (R1), U11.11 (O8)
SYNC: J3.2, J4.2, U4.12 (RCLK), U6.12 (RCLK), U8.12 (RCLK), U10.12 (RCLK)
VCC: C16.1, C18.1, C20.1, C22.1, J3.9, J3.10, J4.9, J4.10, JP1.2 (B), R15.2, U4.16 (VCC), U6.16 (VCC), U8.16 (VCC), U10.16 (VCC)
VDC: C17.1, C19.1, C21.1, C23.1, F1.1, J3.7, J3.8, J4.7, J4.8, TP2.1, U5.9 (VCC), U7.9 (VCC), U9.9 (VCC), U11.9 (VCC)
V_FB: R4.2, RV1.1, U3.5 (Vfb)

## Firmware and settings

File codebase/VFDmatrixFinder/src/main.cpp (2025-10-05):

#include <Arduino.h>
#include <shiftRegVFD.h>
#include <Wire.h>
#include <stdint.h>
#include <string.h>
#include <SPI.h>
#include "ammeterVFD.h"

const uint8_t DATA_PIN = 11;   // pin connected to the data pin of the shift register
const uint8_t STROBE_PIN = 10; // pin connected to the strobe pin of the shift register
const uint8_t CLK_PIN = 13;    // pin connected to the clock pin of the shift register
const int NO_OF_GIDS = 3;
const int NO_OF_SEGS = 56;
const long DELAY = 500;
// this sets the locations of which grids you are updating
const int GRID1 = 0;
const int GRID2 = 1;
const int GRID3 = 2;

int k = 0;
int j = 0;
uint8_t image[128] = {0};
String readString = "";
AmmeterVFD ammeter = AmmeterVFD();

shiftRegVFD display = shiftRegVFD();

// this is frame 231, roughly 7 seconds into the video "bad apple". it is used for testing to make sure the grid bit fiddling is done right
String frame = "111111111101111111111111100001111111111100000011111111111000001111111111110000111111001110000111111110000000011111111100";
// what this frame represents
//   seg1 |  seg2 |  seg3 || serial Data
//  ##### | ##### | .#### || ##########.####
//  ##### | ####. | ...## || #########....##
//  ##### | ###.. | ....# || ########......#
//  ##### | ####. | ....# || #########.....#
//  ##### | ##### | ....# || ##########....#
//  ####. | .###. | ...## || ####..###....##
//  ##### | ..... | ...## || #####........##

uint64_t segList[NO_OF_SEGS] =
    {
        0, 0, 0, 1, 0,
        0, 0, 0, 1, 0,
        0, 0, 0, 1, 0,
        0, 0, 0, 1, 0,
        0, 0, 0, 1, 0,
        0, 0, 0, 1, 0,
        0, 0, 0, 1, 0,
        0, 0, 2, 3, 3,
        3, 3, 3, 3, 3,
        3, 3, 3, 3, 3,
        3, 3, 3, 3, 4,
        4};

static uint64_t matrix[NO_OF_GIDS] = {
    //    Digiets/Segments                           | Grids    |extras
    // 0b1000110001111111000110001100010000000000000000000100000000000000,
    0b1000000010000000100000001000000010000000100000001000000010000000,
    0b0111000100001000010000100011100000000000000000000000000000000000,
    0b1111111111111111111111111111111111111111000011100000001000000000};
bool timing(unsigned long DELAY)
{
  static unsigned long lastTime = 0;
  unsigned long currentTime = millis();

  if (currentTime - lastTime >= DELAY)
  {
    lastTime = currentTime;
    return true; // Interval has passed
  }
  return false;
} // Interval not yet reached

void frameToDisplays(uint16_t *frame)
{
  size_t shiftAmount = 43;

  // Clear old data
  uint64_t displayData[NO_OF_GIDS] = {0};
  // this is specifically NOT a loop to make it as fast as possible
  displayData[0] = (((uint64_t)(frame[0] & 0xF800) << (shiftAmount)) |
                    ((uint64_t)(frame[1] & 0xF800) << (shiftAmount - 5)) |
                    ((uint64_t)(frame[2] & 0xF800) << (shiftAmount - 10)) |
                    ((uint64_t)(frame[3] & 0xF800) << (shiftAmount - 15)) |
                    ((uint64_t)(frame[4] & 0xF800) << (shiftAmount - 20)) |
                    ((uint64_t)(frame[5] & 0xF800) << (shiftAmount - 25)) |
                    ((uint64_t)(frame[6] & 0xE000) << (shiftAmount - 30)) |
                    ((uint64_t)(frame[6] & 0x1800) << (shiftAmount -30)));

  displayData[1] = (((uint64_t)(frame[0] & 0x07C0) << (shiftAmount + 5)) |
                    ((uint64_t)(frame[1] & 0x07C0) << (shiftAmount)) |
                    ((uint64_t)(frame[2] & 0x07C0) << (shiftAmount - 5)) |
                    ((uint64_t)(frame[3] & 0x07C0) << (shiftAmount - 10)) |
                    ((uint64_t)(frame[4] & 0x07C0) << (shiftAmount - 15)) |
                    ((uint64_t)(frame[5] & 0x07C0) << (shiftAmount - 20)) |
                    ((uint64_t)(frame[6] & 0x07C0) << (shiftAmount - 25)) |
                    ((uint64_t)(frame[6] & 0x00C0) << (shiftAmount - 25)));

  displayData[2] = (((uint64_t)(frame[0] & 0x003E) << (shiftAmount + 10)) |
                    ((uint64_t)(frame[1] & 0x003E) << (shiftAmount + 5)) |
                    ((uint64_t)(frame[2] & 0x003E) << (shiftAmount)) |
                    ((uint64_t)(frame[3] & 0x003E) << (shiftAmount - 5)) |
                    ((uint64_t)(frame[4] & 0x003E) << (shiftAmount - 10)) |
                    ((uint64_t)(frame[5] & 0x003E) << (shiftAmount - 15)) |
                    ((uint64_t)(frame[6] & 0x0038) << (shiftAmount - 20)) |
                    ((uint64_t)(frame[6] & 0x0006) << (shiftAmount - 20)));

  // bit masks over the grids to stop too much current being drawn
  // displayData[0] = (displayData[0]<<15 & 0b1111111111111111111111111111111111111111000011100000000000000000);
  // displayData[1] = (displayData[1]<<15 & 0b1111111111111111111111111111111111111111000011100000000000000000);
  // displayData[2] = (displayData[2]<<15 & 0b1111111111111111111111111111111111111111000011100000000000000000);
  // // now mask back over
  // add in the grids on the end
  displayData[0] = (displayData[0] | 0b0000000000000000000000000000000000000000000000000100000000000000);
  displayData[1] = (displayData[1] | 0b0000000000000000000000000000000000000000000000000010000000000000);
  displayData[2] = (displayData[2] | 0b0000000000000000000000000000000000000000000000000000001000000000);

  // now output the data and update the matrix. this is done after in case one bitmask takes slightly longer than the other
  
  // Serial.print(char(displayData[2]),BIN);

  display.updateMatrix(displayData[0], 0);
  display.updateMatrix(displayData[1], 1);
  display.updateMatrix(displayData[2], 2);
  display.outputMatrix(0);
  display.outputMatrix(1);
  display.outputMatrix(2);
}

uint16_t *convertStringToU64(String str)
{

  // with this method you dont have to worry about zeroes, and you just grab what you need
  static uint16_t val[7] = {
      (uint16_t)strtoul(str.substring(0, 16).c_str(), nullptr, 2),
      (uint16_t)strtoul(str.substring(16, 32).c_str(), nullptr, 2),
      (uint16_t)strtoul(str.substring(32, 48).c_str(), nullptr, 2),
      (uint16_t)strtoul(str.substring(48, 64).c_str(), nullptr, 2),
      (uint16_t)strtoul(str.substring(64, 96).c_str(), nullptr, 2),
      (uint16_t)strtoul(str.substring(96, 112).c_str(), nullptr, 2)};
  

for (size_t i = 0; i < 7; i++) {
  int start = i * 16;
  int end = start + 16;
  val[i] = (uint16_t)strtoul(str.substring(start, end).c_str(), nullptr, 2);
}
return val;

}
void setup()
{
  Serial.begin(115200);
  display.begin(DATA_PIN, STROBE_PIN, CLK_PIN, NO_OF_SEGS);
  ammeter.begin(A0, 4, A2, 5);
  ammeter.toHCS();

  display.setMatrix(matrix, NO_OF_GIDS);
  display.outputMatrix(0);
  frameToDisplays(convertStringToU64(frame));
}

void loop()
{

  while (Serial.available())
  {
  

    char c = Serial.read();
    Serial.print(c);
    if (c != '\n') {
      readString += c;
}
    else if (c == '\n')
    {
      frameToDisplays(convertStringToU64(readString));
      
      readString = "";

    }
  } 
    display.outputMatrix(0);
    display.outputMatrix(1);
    display.outputMatrix(2);

  
    

  }

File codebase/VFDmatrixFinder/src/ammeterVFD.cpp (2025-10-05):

#include "Arduino.h"
#include "ammeterVFD.h"
#include "wire.h"


AmmeterVFD::AmmeterVFD() {
    _current = 0;
    _prevCurrent = 0;
    _mode = 0; //start in low current mode
    // 0 is low current mode, 1 is high current
    _lastReadTime = 0;
}
void AmmeterVFD::begin(int hcsIN, int hcsEN, int lcsIN, int lcsEN) {
    _hcsIN = hcsIN;
    _hcsEN = hcsEN;
    _lcsIN = lcsIN;
    _lcsEN = lcsEN;
    _LCSIN2 = lcsIN + 1; //the second low current sensor is always the next pin
    _HCSIN2 = hcsIN + 1; //the second high current sensor is always the next pin

    pinMode(_hcsEN, OUTPUT);
    pinMode(_lcsEN, OUTPUT);
    pinMode(_hcsIN, INPUT);
    pinMode(_lcsIN, INPUT);
    pinMode(_HCSIN2, INPUT); //setup the second high current pin
    pinMode(_LCSIN2, INPUT); //setup the second low current
    digitalWrite(_hcsEN, HIGH); //disable high current sensor
    digitalWrite(_lcsEN, LOW); //enable low current sensor
}
    void AmmeterVFD::toLCS()
    {
        digitalWrite(_hcsEN, HIGH); //disable high current sensor
        digitalWrite(_lcsEN, LOW); //enable low current sensor
        _mode = 0;
    }
    void AmmeterVFD:: toHCS()
    {
        digitalWrite(_hcsEN, LOW); //enable high current sensor
        digitalWrite(_lcsEN, HIGH); //disable low current sensor
        _mode = 1;
    }
    float AmmeterVFD:: readCurrent()
    {
        if(_mode == 0) {
            return analogRead(_lcsIN);
        } else {
            return analogRead(_hcsIN);
        }
    }

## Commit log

2025-08-26 add electronics directory
    [P-SOP18-0812-1p27-001_TOS.step, cost_bom.csv, spm7054vt-d.step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]
2025-08-26 Fixed ERC and DRC
    [vvfd.kicad_pcb, vvfd.kicad_sch]
2025-08-26 Fix cascade IDC connector
    The cascade input and output IDC pins didn't correspond before
    [vvfd.kicad_pcb, vvfd.kicad_sch]
2025-08-27 made a shield extension for the ardiuno uno board
    ditto
    [UCArduinoShieldTemplate.kicad_pcb, UCArduinoShieldTemplate.kicad_sch]
2025-08-28 added the unos code
    added what should be a basic working version of the arduino unos code.
    [UCArduinoShieldTemplate.kicad_sch]
2025-08-28 bug fixes
    the code now builds properly
    [main.cpp, shiftRegVFD.cpp]
2025-09-01 Added filament timer
    Added a timer to control the filament h-brdige on the main PCB.
    Also added some more decoupling capacitors, but some have dubious
    placement. Still better than nothing.
    [vfd_drive.kicad_sch, vvfd.kicad_pcb, vvfd.kicad_sch]
2025-09-03 added conversion kit
    added a conversion kit and some light code adding
    [conversion board-B_Cu.gbr, conversion board-B_Mask.gbr, conversion board-B_Silkscreen.gbr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]
2025-09-04 Added VFD output pulldowns
    Added pulldowns and more decoupling capacitors. The capacitors and
    pulldowns can probably be omitted, but I've put them in for more flexibility.
    [vfd_drive.kicad_sch, vvfd.csv, vvfd.kicad_pcb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]
2025-09-07 Fixed H-bridge
    Old H-bridge was the wrong type, changed to using some P-channel
    mosfets. Also fixed the cost spreadsheet.
    [cost_bom.csv, cost_bom.ods, vfd_drive.kicad_sch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]
2025-09-08 Added timer circuit test picture
    Added a picture of the timer circuits output recorded on an oscilloscope
    [cost_bom.ods, vvfd.csv, vvfd.kicad_sch]
2025-09-14 Updated BOM
    Updated BOMs because some of the component prices changed and a part
    went out of stock.
    [cost_bom.ods, vfd_drive.kicad_sch, vvfd.csv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]
2025-09-17 Prepared driverboard for export
    [ENEL200Group05.csv, P-SOP18-0812-1p27-001_TOS.step, cost_bom.ods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]
2025-09-18 Minor PCB rev
    Moved shift register bypass caps around a bit. Also changed a price on
    the BOM, that's the final change before the digikey parts order is in.
    [cost_bom.ods, driverboard.csv, driverboard.kicad_pcb]
2025-10-03 Fixed H-bridge timer
    The H-bridge timer had no blank time on a clock transition before, this
    would cause a momentary short circuit as the mosfet switching times
    aren't instant. To fix this an extra 555 timer stage was added.
    [cost_bom.ods, driverboard.csv, driverboard.kicad_pcb]
2025-10-05 Updated shield
    Also made driver board a bit tider
    [UCArduinoShieldTemplate.kicad_pcb, UCArduinoShieldTemplate.kicad_sch, VVFDShield.kicad_pcb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]
2025-10-05 Added current sensing demo
    Added that and useful debugging code to a new folder.
    Sam can use the parts he need or delete it in the future.
2025-10-08 Removed Current Sensing
    Removed current sensing, because it would require a major design
    overhaul to work properly.
    [VVFDShield.kicad_pcb, VVFDShield.kicad_sch, cost_bom.ods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]
